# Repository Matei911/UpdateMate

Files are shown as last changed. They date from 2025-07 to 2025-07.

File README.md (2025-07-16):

# UpdateMate

**UpdateMate** is an open-source, low-power ePaper tablet designed for tinkerers, developers, and DIY enthusiasts.  
Built around the ESP32 microcontroller, it offers a customizable platform for displaying relevant, distraction-free information — from weather forecasts and calendar events to news, sensor data, and more.

## Preview

<table>
  <tr>
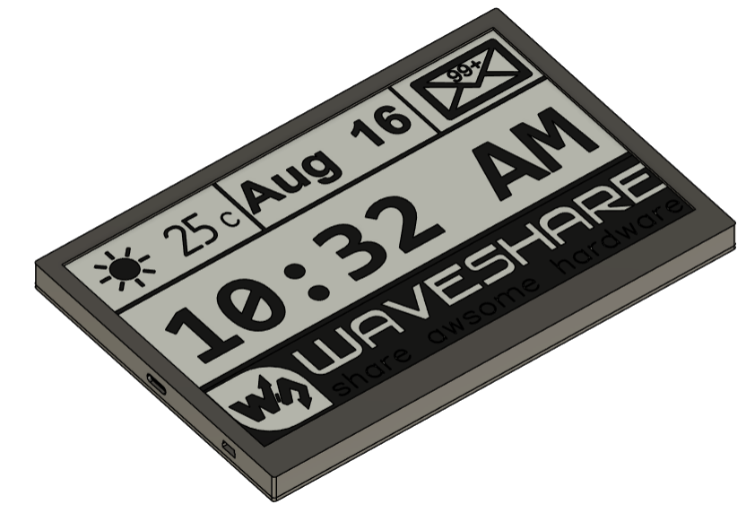
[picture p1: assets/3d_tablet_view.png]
    <td align="center"><br/><sub>3D View of Tablet</sub></td>
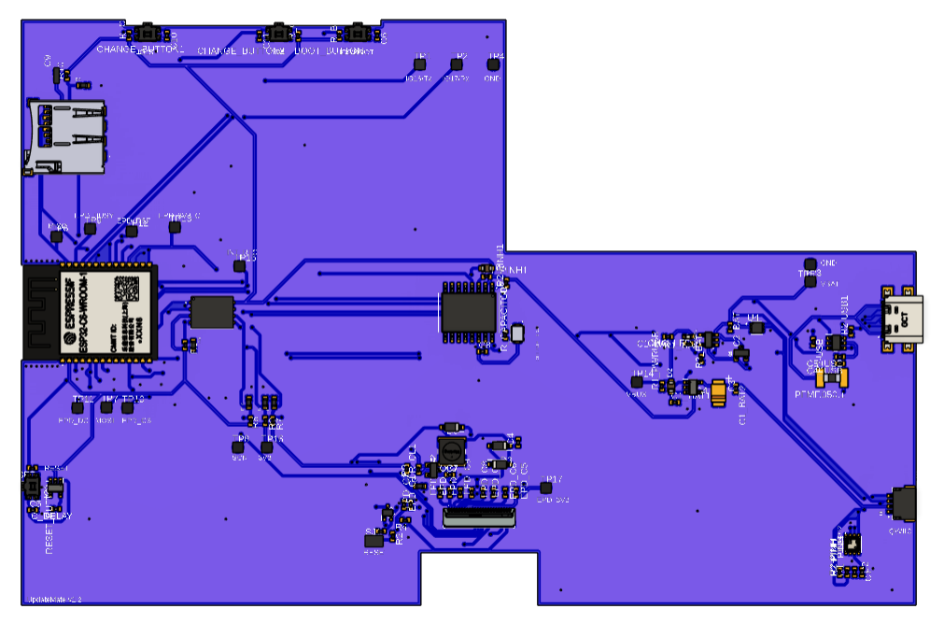
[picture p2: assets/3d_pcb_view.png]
    <td align="center"><br/><sub>3D View of PCB</sub></td>
  </tr>
  <tr>
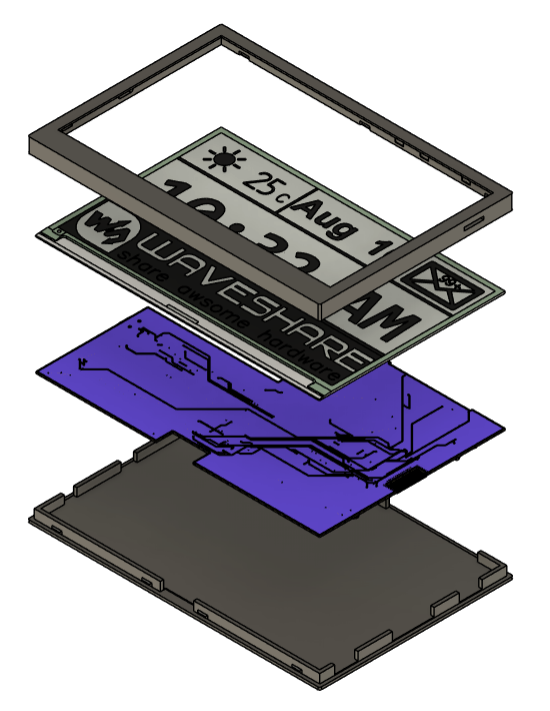
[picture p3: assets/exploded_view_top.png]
    <td align="center"><br/><sub>Exploded View (Top)</sub></td>
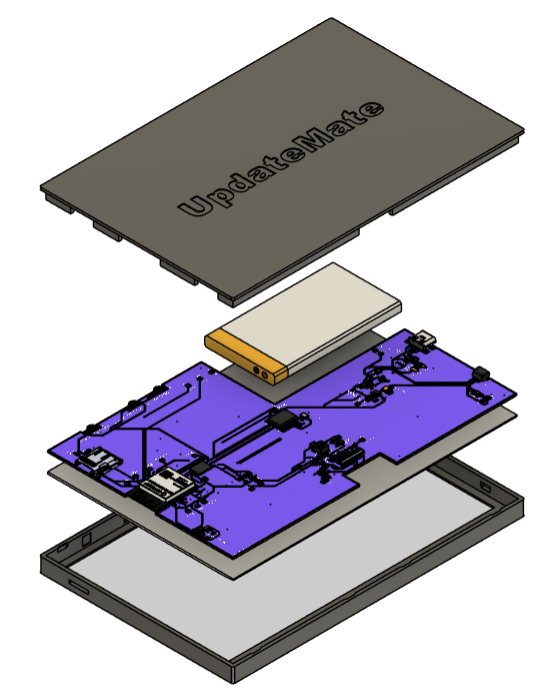
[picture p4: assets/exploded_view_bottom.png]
    <td align="center"><br/><sub>Exploded View (Bottom)</sub></td>
  </tr>
</table>

## Features

- 🖥️ 7.5-inch black-and-white ePaper display from Waveshare  
- ⚡ Low power consumption with deep sleep support  
- 🧩 Rich peripheral support: sensors, SD card, RTC, fuel gauge, and more  
- 🔧 Designed for customization: easily add your own widgets, components, or software

## Ideal for

- 📖 eBook and tablet replacements  
- 🏡 Smart home dashboards  
- 🌦️ Always-on weather/news displays  
- 📅 Personal productivity boards  
- 📡 IoT project front-ends  
- 🧪 Educational embedded systems kits

## Bill of Materials (BoM)

The main components in the tablet

| Component | Interface | Description | Link |
|---|---|---|---|
| **ESP32-C6-WROOM-1-N4**| MCU | Main microcontroller | [Mouser](https://eu.mouser.com/ProductDetail/Espressif-Systems/ESP32-C6-WROOM-1-N4?qs=8Wlm6%252BaMh8R1JRAtXlt87w%3D%3D) |
| **7.5" Waveshare ePaper** | SPI | Black-and-white e-paper display | [Waveshare](https://www.waveshare.com/7.5inch-e-paper.htm) |
| **MicroSD Card Socket** | SPI | For storage and data logging | [TME](https://www.tme.eu/ro/details/mcc-sdmicro/conectori-pentru-cartele/attend/112a-taar-r03/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) |
| **W25Q512JVEIQ NOR Flash** | SPI  | 64 MB external flash memory | [Mouser](https://eu.mouser.com/ProductDetail/Winbond/W25Q512JVEIQ?qs=l7cgNqFNU1jw6svr3at6tA%3D%3D) |
| **MAX17048 Fuel Gauge** | I2C | Battery voltage and state-of-charge monitor | [Mouser](https://eu.mouser.com/ProductDetail/Analog-Devices-Maxim-Integrated/MAX17048G%2bT10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) |
| **BME680 Sensor Board** | I2C | Environmental sensor (temp, humidity, gas)  | [Mouser](https://eu.mouser.com/ProductDetail/Bosch-Sensortec/BME680-Shuttle-Board-3.0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) |
| **DS3231SN RTC** | I2C | Real-time clock with temperature compensation | [Mouser](https://eu.mouser.com/ProductDetail/Analog-Devices-Maxim-Integrated/DS3231SN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) |

## Gallery

Pictures with the features already implemented on the tablet.

<table>
  <tr>
    <td align="center">
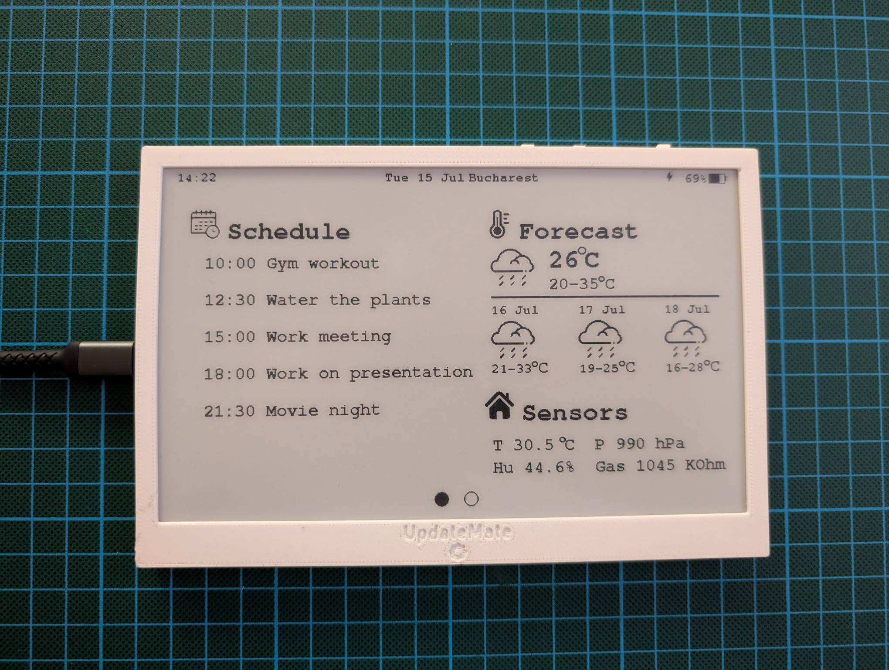
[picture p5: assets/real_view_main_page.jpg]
      <br/>
      <sub>Main Page View</sub>
    </td>
    <td align="center">
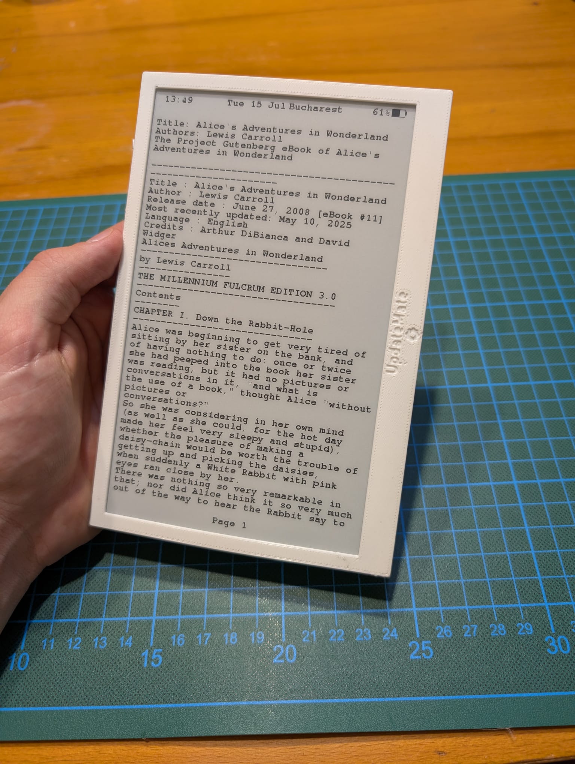
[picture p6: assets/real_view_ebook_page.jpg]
      <br/>
      <sub>eBook Page View</sub>
    </td>
    <td align="center">
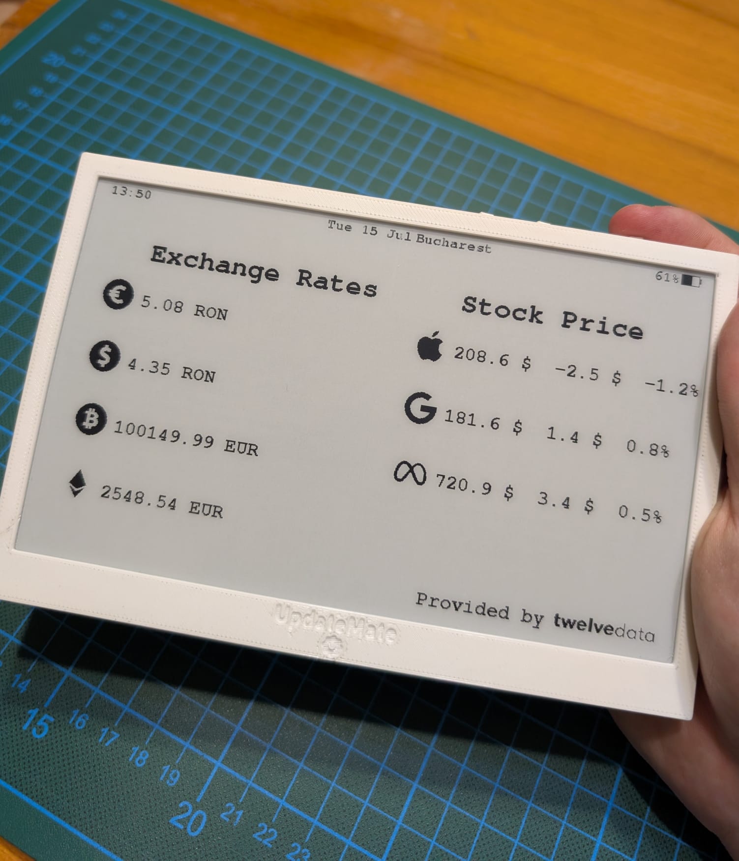
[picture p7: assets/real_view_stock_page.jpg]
      <br/>
      <sub>Stock Page View</sub>
    </td>
  </tr>
  <tr>
    <td align="center">
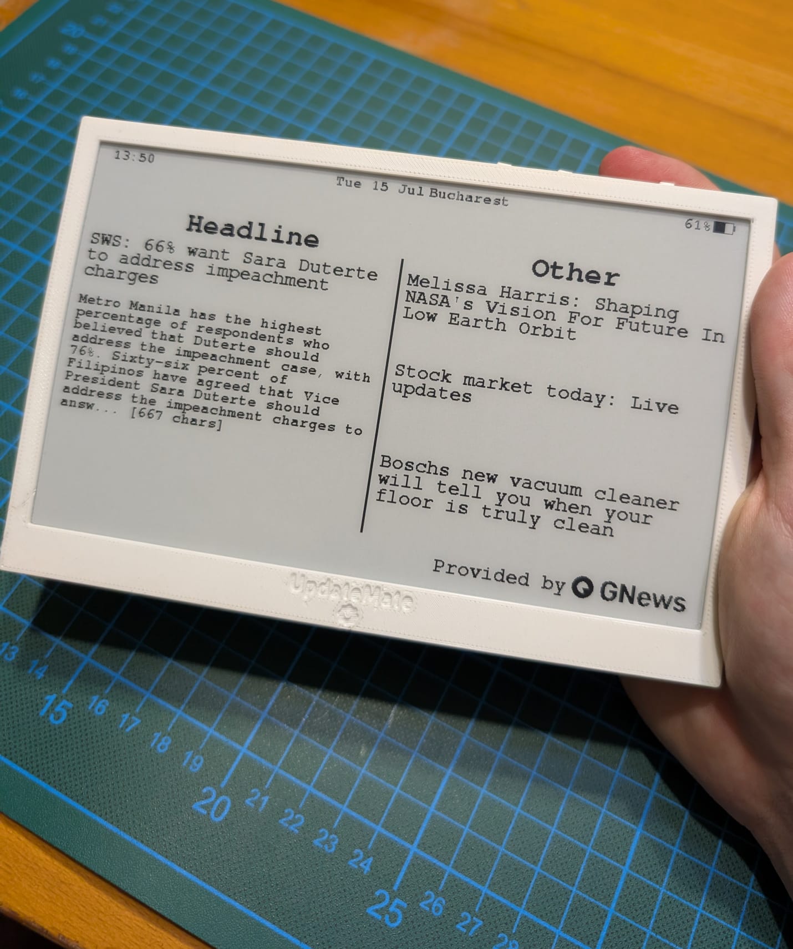
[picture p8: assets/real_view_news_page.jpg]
      <br/>
      <sub>News Page View</sub>
    </td>
    <td align="center">
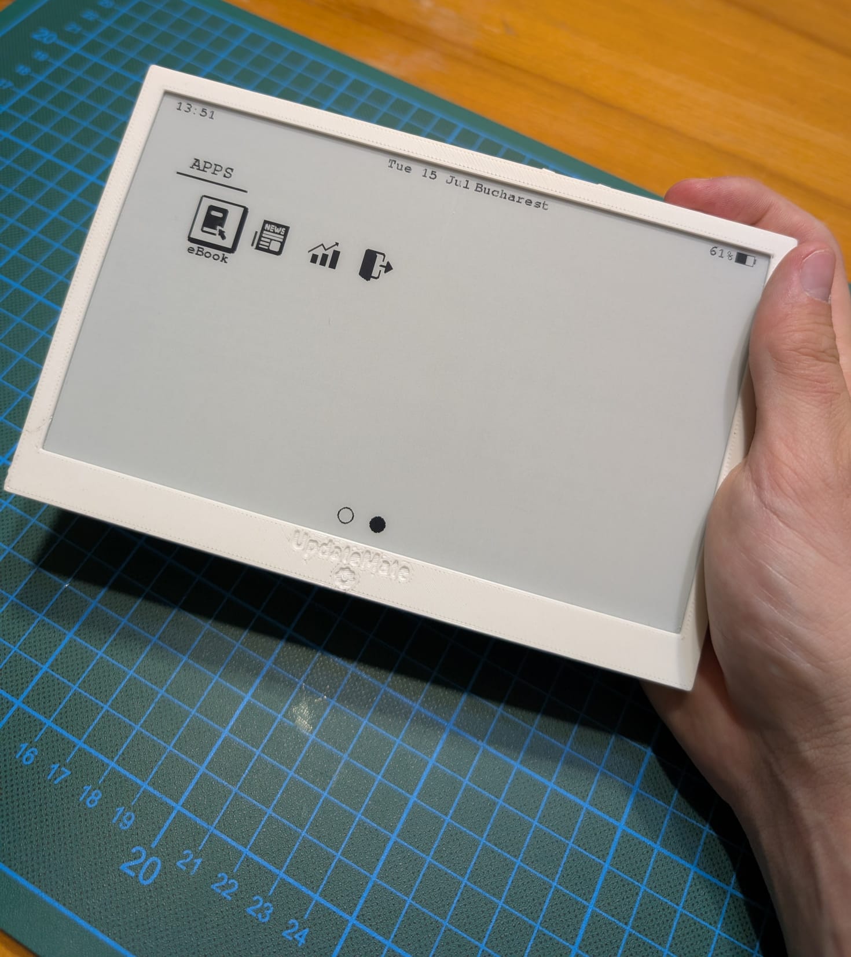
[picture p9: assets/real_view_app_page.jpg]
      <br/>
      <sub>App Launcher View</sub>
    </td>
    <td align="center">
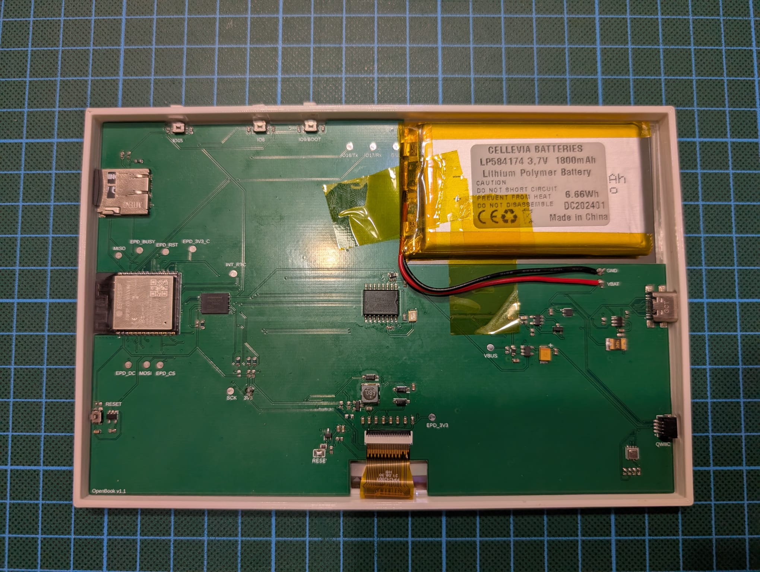
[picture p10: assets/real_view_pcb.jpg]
      <br/>
      <sub>PCB inside case</sub>
    </td>
  </tr>
</table>

## Contents

The repository is structured into two main sections:

### `/hardware`
- Autodesk Fusion 360 design files for the custom PCB  
- 3D model files for the full tablet case, including STL/STEP formats for printing or editing  
- Schematics and layout files for manufacturing the board

### `/software`
- Arduino sketches for individual components (e.g. display, sensors, Wi-Fi, etc.) for testing  
- Full firmware implementation for the UpdateMate tablet, enabling all features shown in the gallery (weather, news, stocks, calendar, eBooks)

**Enjoy tinkering!**

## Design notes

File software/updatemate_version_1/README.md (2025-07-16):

## About This Code 

These files contain the source code for the **UpdateMate tablet**, as featured in the exposed images. The current version supports several core features, including:

- 📅 Google Calendar event display  
- 🌦️ Weather updates  
- 📰 News headlines  
- 📈 Stock price monitoring  
- 📖 Basic eBook reading functionality

Feel free to use the code as-is, customize it for your needs, or improve it.

---

## Before You Flash the Firmware

Please review the following setup requirements:

1. **Partition Scheme**  
   Use the **2MB app / 2MB SPIFFS** partition scheme in your Arduino IDE alonside **ESP32C6 Dev Module**

2. **Uploading Icons**  
   Icon files must be uploaded via the SPIFFS filesystem. This requires an older version of the Arduino IDE.  
   👉 Follow this guide: [Install ESP32 Filesystem Uploader](https://randomnerdtutorials.com/install-esp32-filesystem-uploader-arduino-ide/)

3. **eBook Support**  
   Only `.txt` books are supported in the current version!  
   📚 Visit [Project Gutenberg](https://www.gutenberg.org/) to download free public domain books, then use the provided Python script to convert and upload them.

4. **Google Calendar Integration**  
   You’ll need a custom **Google Apps Script** to expose a private URL that serves your calendar data.  
   ✍️ A template script is included in the repository.

5. **API Keys Required**  
   The following services are used for fetching dynamic data:
   - [Visual Crossing](https://www.visualcrossing.com/) – for weather
   - [Twelve Data](https://twelvedata.com/) – for stock prices
   - [GNews](https://gnews.io/) – for news feed

   🗝️ Sign up for these services to obtain the necessary API keys and insert them into the configuration file.

6. **Enjoy tinkering!**

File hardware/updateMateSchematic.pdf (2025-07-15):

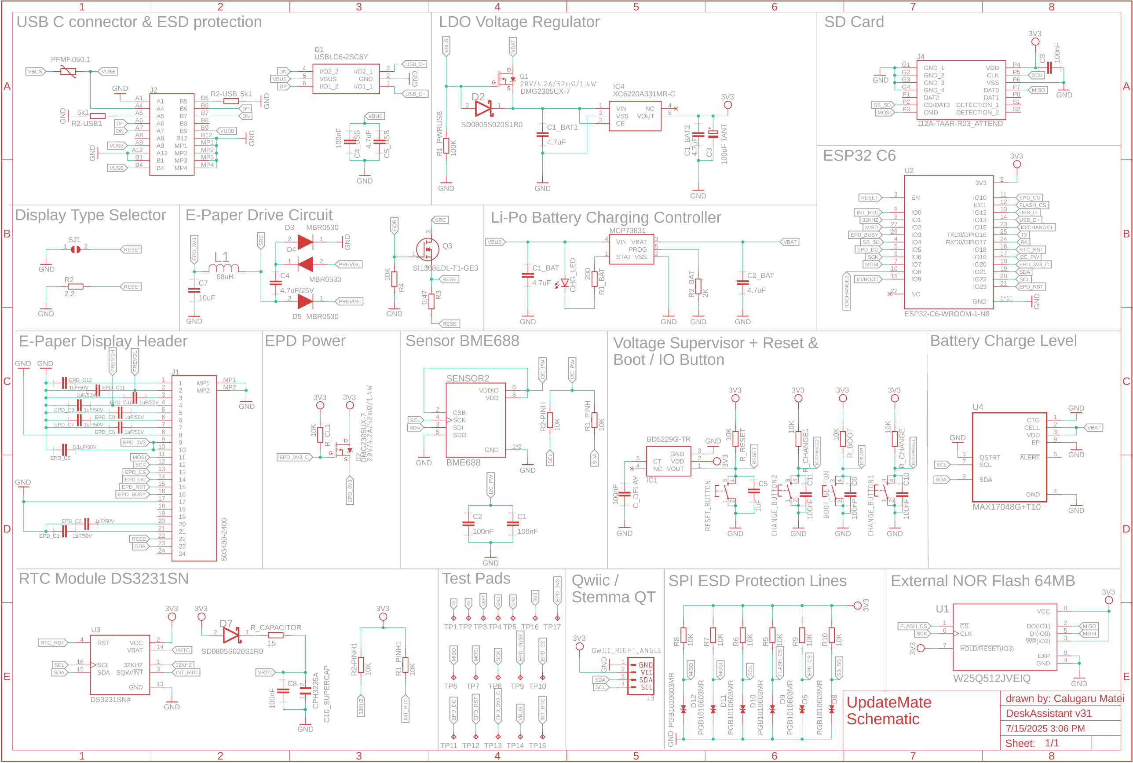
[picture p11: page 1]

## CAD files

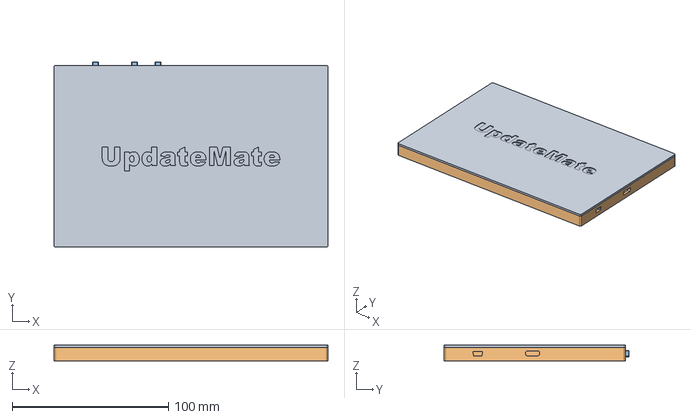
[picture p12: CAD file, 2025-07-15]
hardware/updateMateBox.step
175.2 x 118.5 x 10.2 mm

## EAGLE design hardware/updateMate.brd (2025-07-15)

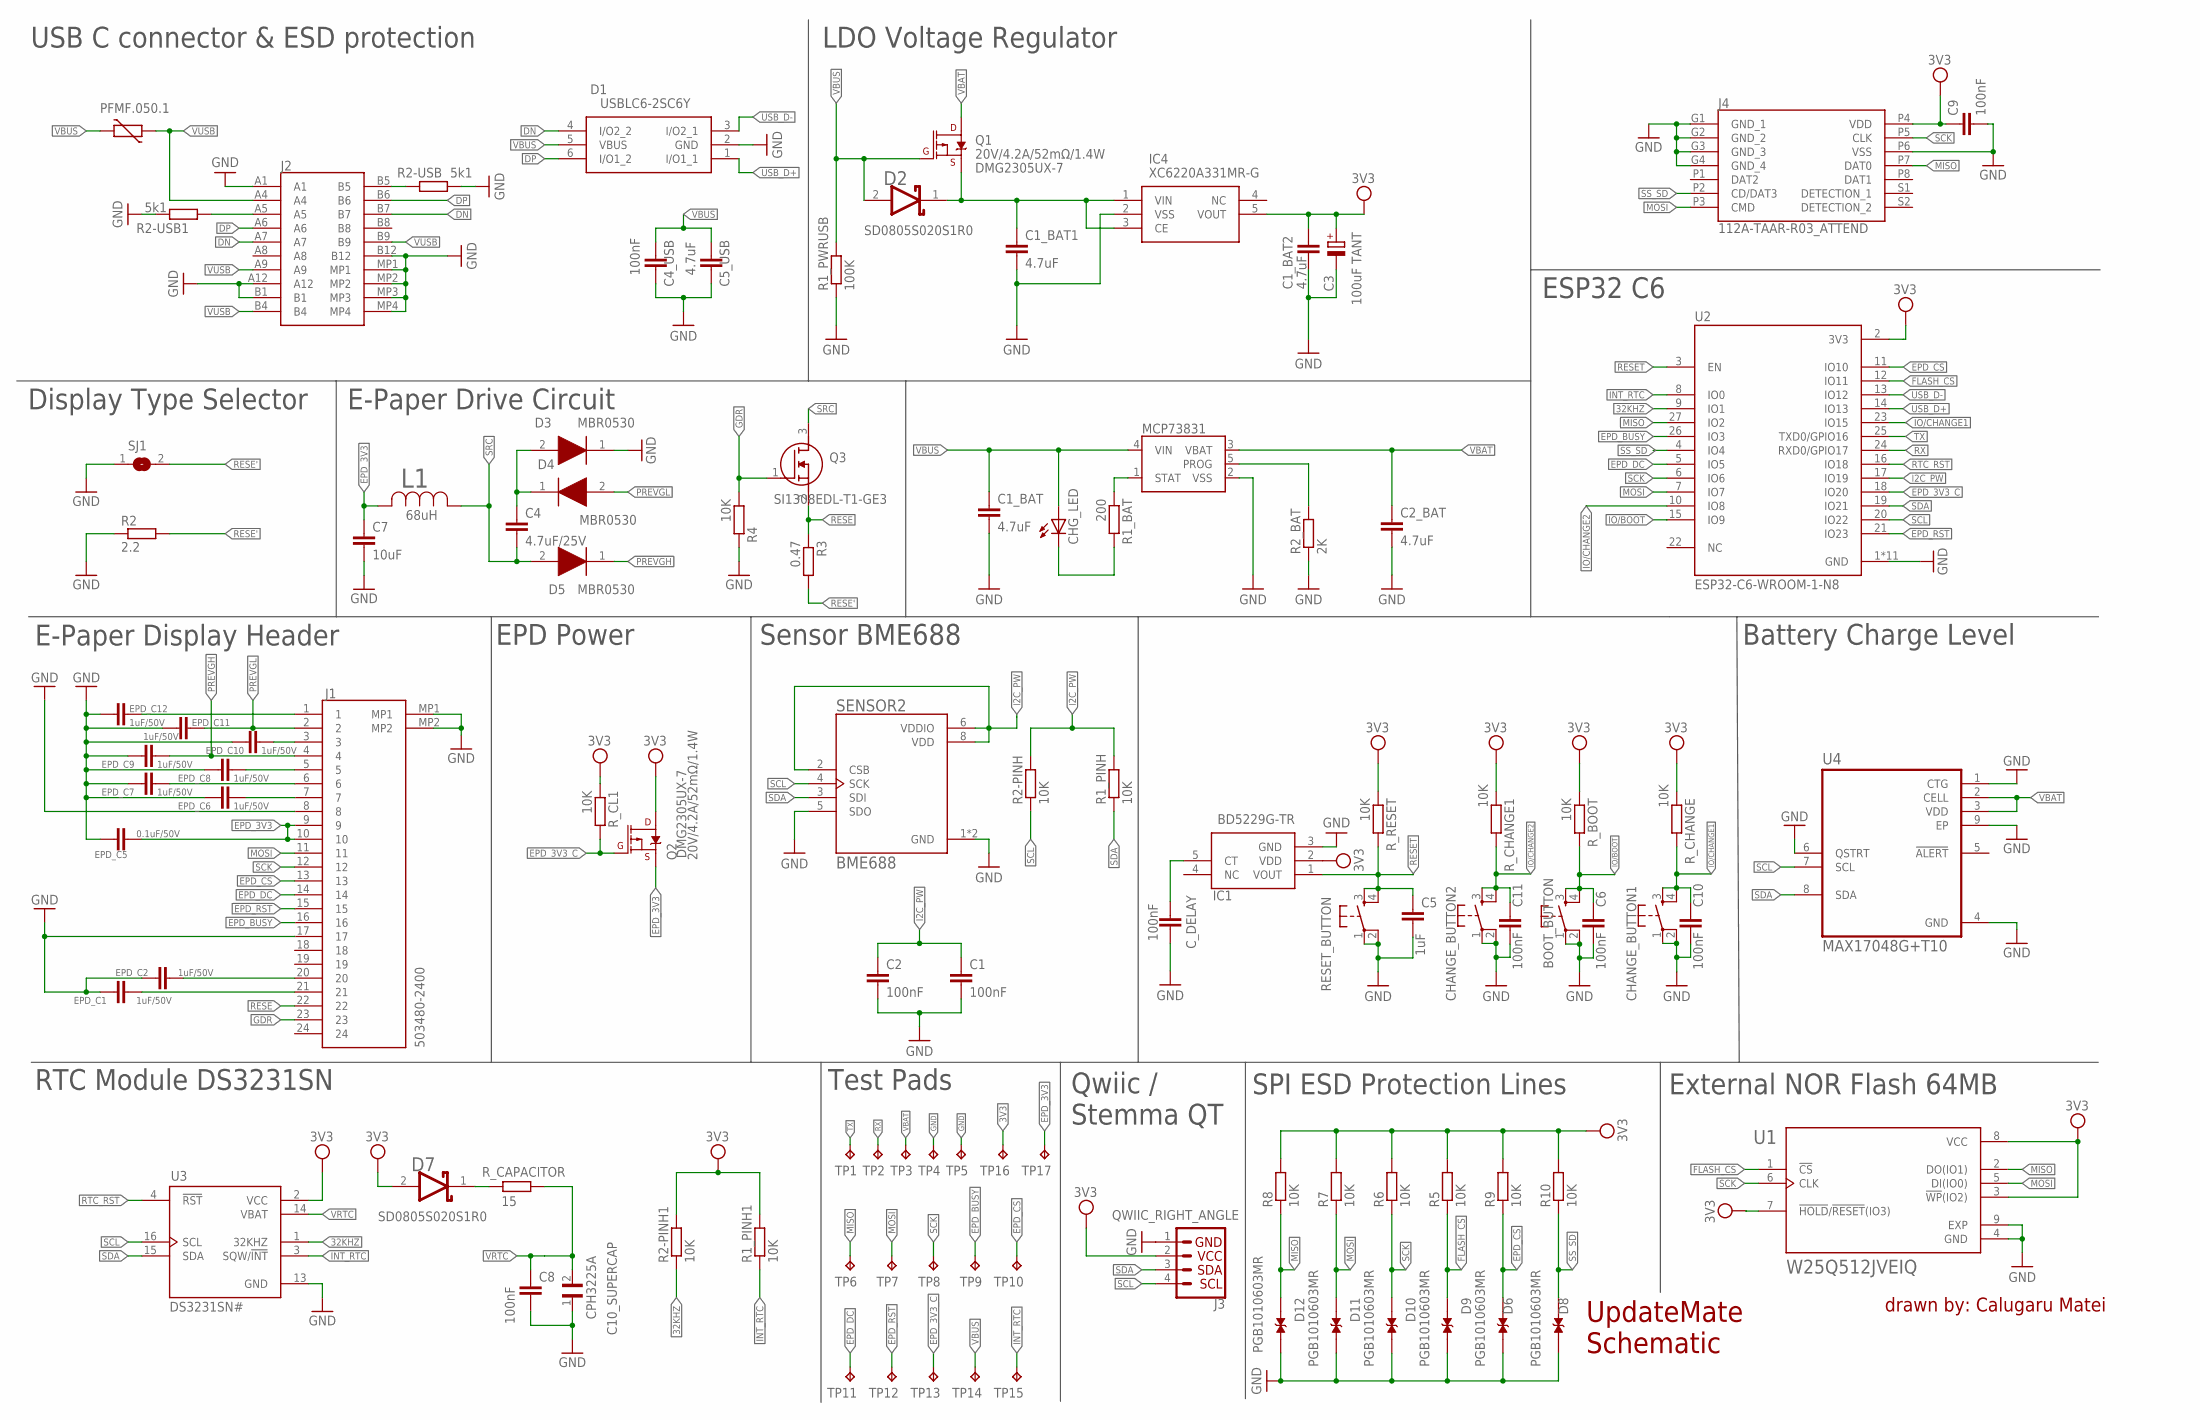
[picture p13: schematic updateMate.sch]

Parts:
BOOT_BUTTON: BUTTON_CUSYOMV1; MYBUTTON
C1, C2, C4_USB, C6, C8, C10, C11: 100nF; ESP32_WROVER_EAGLE-LTSPICE_C0402
C1_BAT, C1_BAT1, C1_BAT2, C2_BAT, C5_USB: 4.7uF; ESP32_WROVER_EAGLE-LTSPICE_C0402
C3: 100uF TANT; RCL_CT3528
C4: 4.7uF/25V; ESP32_WROVER_EAGLE-LTSPICE_C0402
C5: 1uF; ESP32_WROVER_EAGLE-LTSPICE_C0402
C7: 10uF; ESP32_WROVER_EAGLE-LTSPICE_C0402
C9: 100nF; EAGLE-LTSPICE_C0402
C10_SUPERCAP: CPH3225A; CAPCP3225X100N
CHANGE_BUTTON1, CHANGE_BUTTON2: BUTTON_CUSYOMV1; MYBUTTON
CHG_LED: ADAFRUIT_LEDCHIP-LED0603; ADAFRUIT_CHIP-LED0603
C_DELAY: 100nF; ESP32_WROVER_EAGLE-LTSPICE_C0402
D1: USBLC6-2SC6Y; SOT95P280X145-6N
D2: ESP32_WROVER_AVX---SD0805S020S1R0_AVX_SD0805S020S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; ESP32_WROVER_AVX---SD0805S020S1R0_AVX_SD0805S020S1R0_0
D3, D4, D5: MBR0530; SOD3716X135N
D6, D8, D9, D10, D11, D12: PGB1010603MR; DIOC1608X36N
D7: SD0805S020S1R0; ESP32_WROVER_AVX---SD0805S020S1R0_AVX_SD0805S020S1R0_0
EPD_C1, EPD_C2, EPD_C6, EPD_C7, EPD_C8, EPD_C9, EPD_C10, EPD_C11, EPD_C12: 1uF/50V; ESP32_WROVER_EAGLE-LTSPICE_C0402
EPD_C5: 0.1uF/50V; ESP32_WROVER_EAGLE-LTSPICE_C0402
IC1: BD5229G-TR; SOT95P280X125-5N
IC4: XC6220A331MR-G; SOT95P280X120-5N
J1: 503480-2400; 5034802400
J2: SAMACSYS_PARTS_USB4110-GF-A; SAMACSYS_PARTS_USB4110GFA
J3: QWIIC_RIGHT_ANGLE; JST04_1MM_RA
J4: 112A-TAAR-R03_ATTEND; 112ATAARR03ATTEND
L1: 68uH; IND_4828-WE-TPC_WRE
MCP73831: ESP32_WROVER_SPARKFUN-IC-POWER_MCP73831; ESP32_WROVER_SPARKFUN-IC-POWER_SOT23-5
PFMF.050.1: ESP32C6_VARISTORCN1812; ESP32C6_VARISTOR_CT/CN1812
Q1, Q2: 20V/4.2A/52mΩ/1.4W; ESP32_WROVER_SPARKFUN-DISCRETESEMI_SOT23-3
Q3: SI1308EDL-T1-GE3; SOT65P210X110-3N
R1_BAT: 200; ESP32_WROVER_EAGLE-LTSPICE_R0402
R1_PINH, R1_PINH1, R2-PINH, R2-PINH1, R4, R5, R6, R7, R8, R9, R10: 10K; ESP32_WROVER_EAGLE-LTSPICE_R0402
R1_PWRUSB: 100K; ESP32_WROVER_EAGLE-LTSPICE_R0402
R2: 2.2; ESP32_WROVER_EAGLE-LTSPICE_R0402
R2-USB, R2-USB1: 5k1; ESP32_WROVER_EAGLE-LTSPICE_R0402
R2_BAT: 2K; ESP32_WROVER_EAGLE-LTSPICE_R0402
R3: 0.47; ESP32_WROVER_EAGLE-LTSPICE_R0402
RESET_BUTTON: BUTTON_CUSYOMV1; MYBUTTON
R_BOOT: 10K; ESP32_WROVER_EAGLE-LTSPICE_R0402
R_CAPACITOR: 15; ESP32_WROVER_EAGLE-LTSPICE_R0402
R_CHANGE, R_CHANGE1: 10K; ESP32_WROVER_EAGLE-LTSPICE_R0402
R_CL1: 10K; ESP32_WROVER_EAGLE-LTSPICE_R0402
R_RESET: 10K; ESP32_WROVER_EAGLE-LTSPICE_R0402
SENSOR2: BME688; ESP32_WROVER_BME680_PSON80P300X300X100-8N
SJ1: SJ
TP1, TP2, TP3, TP4, TP5, TP6, TP7, TP8, TP9, TP10, TP11, TP12, TP13, TP14, TP15, TP16, TP17: TPTP20R; TP20R
U1: W25Q512JVEIQ; SON127P600X800X80-9N
U2: ESP32-C6-WROOM-1-N8; XCVR_ESP32-C6-WROOM-1-N8
U3: DS3231SN#; SOIC127P1032X265-16N
U4: MAX17048G+T10; SON50P200X200X80-9N

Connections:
3V3: C1_BAT2.1, C3.+, C9.1, D7.2 (ANODE), IC1.2 (VDD), IC4.5 (VOUT), J3.2, J4.P4 (VDD), Q2.3 (D), R1_PINH1.2, R2-PINH1.2, R5.2, R6.2, R7.2, R8.2, R9.2, R10.2, R_BOOT.1, R_CHANGE.1, R_CHANGE1.1, R_CL1.1, R_RESET.1, TP16.TP, U1.3 (!WP!(IO2)), U1.7 (!HOLD!/!RESET!(IO3)), U1.8 (VCC), U2.2 (3V3), U3.2 (VCC)
32KHZ: R2-PINH1.1, U2.9 (IO1), U3.1 (32KHZ)
DN: D1.4 (I/O2_2), J2.A7, J2.B7
DP: D1.6 (I/O1_2), J2.A6, J2.B6
EPD_3V3: C7.1, EPD_C5.1, J1.9, J1.10, L1.2, Q2.2 (S), TP17.TP
EPD_3V3_C: Q2.1 (G), R_CL1.2, TP13.TP, U2.18 (IO20)
EPD_BUSY: J1.16, TP9.TP, U2.26 (IO3)
EPD_CS: D6.1, J1.13, R9.1, TP10.TP, U2.11 (IO10)
EPD_DC: J1.14, TP11.TP, U2.5 (IO5)
EPD_RST: J1.15, TP12.TP, U2.21 (IO23)
FLASH_CS: D9.1, R5.1, U1.1 (!CS), U2.12 (IO11)
GDR: J1.23, Q3.1 (G), R4.1
GND: BOOT_BUTTON.1, BOOT_BUTTON.2, C1.2, C1_BAT.2, C1_BAT1.2, C1_BAT2.2, C2.2, C2_BAT.2, C3.-, C4_USB.2, C5.2, C5_USB.2, C6.2, C7.2, C8.2, C9.2, C10.2, C10_SUPERCAP.1, C11.2, CHANGE_BUTTON1.1, CHANGE_BUTTON1.2, CHANGE_BUTTON2.1, CHANGE_BUTTON2.2, C_DELAY.2, D1.2 (GND), D3.1 (K), D6.2, D8.2, D9.2, D10.2, D11.2, D12.2, EPD_C1.2, EPD_C2.2, EPD_C5.2, EPD_C6.2, EPD_C7.2, EPD_C8.2, EPD_C9.2, EPD_C10.2, EPD_C11.2, EPD_C12.2, IC1.3 (GND), IC4.2 (VSS), J1.8, J1.17, J1.MP1, J1.MP2, J2.A1, J2.A12, J2.B1, J2.B12, J2.MP1, J2.MP2, J2.MP3, J2.MP4, J3.1, J4.G1 (GND_1), J4.G2 (GND_2), J4.G3 (GND_3), J4.G4 (GND_4), J4.P6 (VSS), MCP73831.2 (VSS), R1_PWRUSB.1, R2.1, R2-USB.2, R2-USB1.1, R2_BAT.1, R4.2, RESET_BUTTON.1, RESET_BUTTON.2, SENSOR2.1 (GND), SENSOR2.5 (SDO), SENSOR2.7 (GND), SJ1.1, TP4.TP, TP5.TP, U1.4 (GND), U1.9 (EXP), U2.1 (GND), U2.28 (GND), U2.29_1 (GND), U2.29_2 (GND), U2.29_3 (GND), U2.29_4 (GND), U2.29_5 (GND), U2.29_6 (GND), U2.29_7 (GND), U2.29_8 (GND), U2.29_9 (GND), U3.13 (GND), U4.1 (CTG), U4.4 (GND), U4.6 (QSTRT), U4.9 (EP)
I2C_PW: C1.1, C2.1, R1_PINH.2, R2-PINH.2, SENSOR2.2 (CSB), SENSOR2.6 (VDDIO), SENSOR2.8 (VDD), U2.17 (IO19)
INT_RTC: R1_PINH1.1, TP15.TP, U2.8 (IO0), U3.3 (SQW/!INT)
IO/BOOT: BOOT_BUTTON.3, BOOT_BUTTON.4, C6.1, R_BOOT.2, U2.15 (IO9)
IO/CHANGE1: C10.1, CHANGE_BUTTON1.3, CHANGE_BUTTON1.4, R_CHANGE.2, U2.23 (IO15)
IO/CHANGE2: C11.1, CHANGE_BUTTON2.3, CHANGE_BUTTON2.4, R_CHANGE1.2, U2.10 (IO8)
MISO: D12.1, J4.P7 (DAT0), R8.1, TP6.TP, U1.2 (DO(IO1)), U2.27 (IO2)
MOSI: D11.1, J1.11, J4.P3 (CMD), R7.1, TP7.TP, U1.5 (DI(IO0)), U2.7 (IO7)
unnamed: J2.B5, R2-USB.1
unnamed: C_DELAY.1, IC1.5 (CT)
unnamed: C1_BAT1.1, D2.1 (CATHODE), IC4.1 (VIN), IC4.3 (CE), Q1.2 (S)
unnamed: J2.A5, R2-USB1.2
unnamed: D7.1 (CATHODE), R_CAPACITOR.2
unnamed: EPD_C1.1, J1.21
unnamed: EPD_C2.1, J1.20
unnamed: C4.1, D3.2 (A), D4.1 (K)
unnamed: MCP73831.5 (PROG), R2_BAT.2
unnamed: MCP73831.1 (STAT), R1_BAT.1
unnamed: CHG_LED.C, R1_BAT.2
unnamed: EPD_C6.1, J1.7
unnamed: EPD_C7.1, J1.6
unnamed: EPD_C8.1, J1.5
unnamed: EPD_C10.1, J1.3
unnamed: EPD_C12.1, J1.1
PREVGH: D5.1 (K), EPD_C9.1, J1.4
PREVGL: D4.2 (A), EPD_C11.1, J1.2
RESE: J1.22, Q3.2 (S), R3.1
RESE': R2.2, R3.2, SJ1.2
RESET: C5.1, IC1.1 (VOUT), RESET_BUTTON.3, RESET_BUTTON.4, R_RESET.2, U2.3 (EN)
RTC_RST: U2.16 (IO18), U3.4 (!RST)
RX: TP2.TP, U2.24 (RXD0/GPIO17)
SCK: D10.1, J1.12, J4.P5 (CLK), R6.1, TP8.TP, U1.6 (CLK), U2.6 (IO6)
SCL: J3.4, R2-PINH.1, SENSOR2.4 (SCK), U2.20 (IO22), U3.16 (SCL), U4.7 (SCL)
SDA: J3.3, R1_PINH.1, SENSOR2.3 (SDI), U2.19 (IO21), U3.15 (SDA), U4.8 (SDA)
SRC: C4.2, D5.2 (A), L1.1, Q3.3 (D)
SS_SD: D8.1, J4.P2 (CD/DAT3), R10.1, U2.4 (IO4)
TX: TP1.TP, U2.25 (TXD0/GPIO16)
USB_D+: D1.1 (I/O1_1), U2.14 (IO13)
USB_D-: D1.3 (I/O2_1), U2.13 (IO12)
VBAT: C2_BAT.1, MCP73831.3 (VBAT), Q1.3 (D), TP3.TP, U4.2 (CELL), U4.3 (VDD)
VBUS: C1_BAT.1, C4_USB.1, C5_USB.1, CHG_LED.A, D1.5 (VBUS), D2.2 (ANODE), MCP73831.4 (VIN), PFMF.050.1.1, Q1.1 (G), R1_PWRUSB.2, TP14.TP
VRTC: C8.1, C10_SUPERCAP.2, R_CAPACITOR.1, U3.14 (VBAT)
VUSB: J2.A4, J2.A9, J2.B4, J2.B9, PFMF.050.1.2

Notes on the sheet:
USB C connector & ESD protection
LDO Voltage Regulator
Battery Charge Level
Sensor BME688
ESP32 C6
Qwiic / Stemma QT
External NOR Flash 64MB
E-Paper Display Header
Display Type Selector
E-Paper Drive Circuit
SPI ESD Protection Lines
EPD Power
RTC Module DS3231SN
Test Pads
SD0805S020S1R0
68uH
drawn by: Calugaru Matei
UpdateMate Schematic
DMG2305UX-7

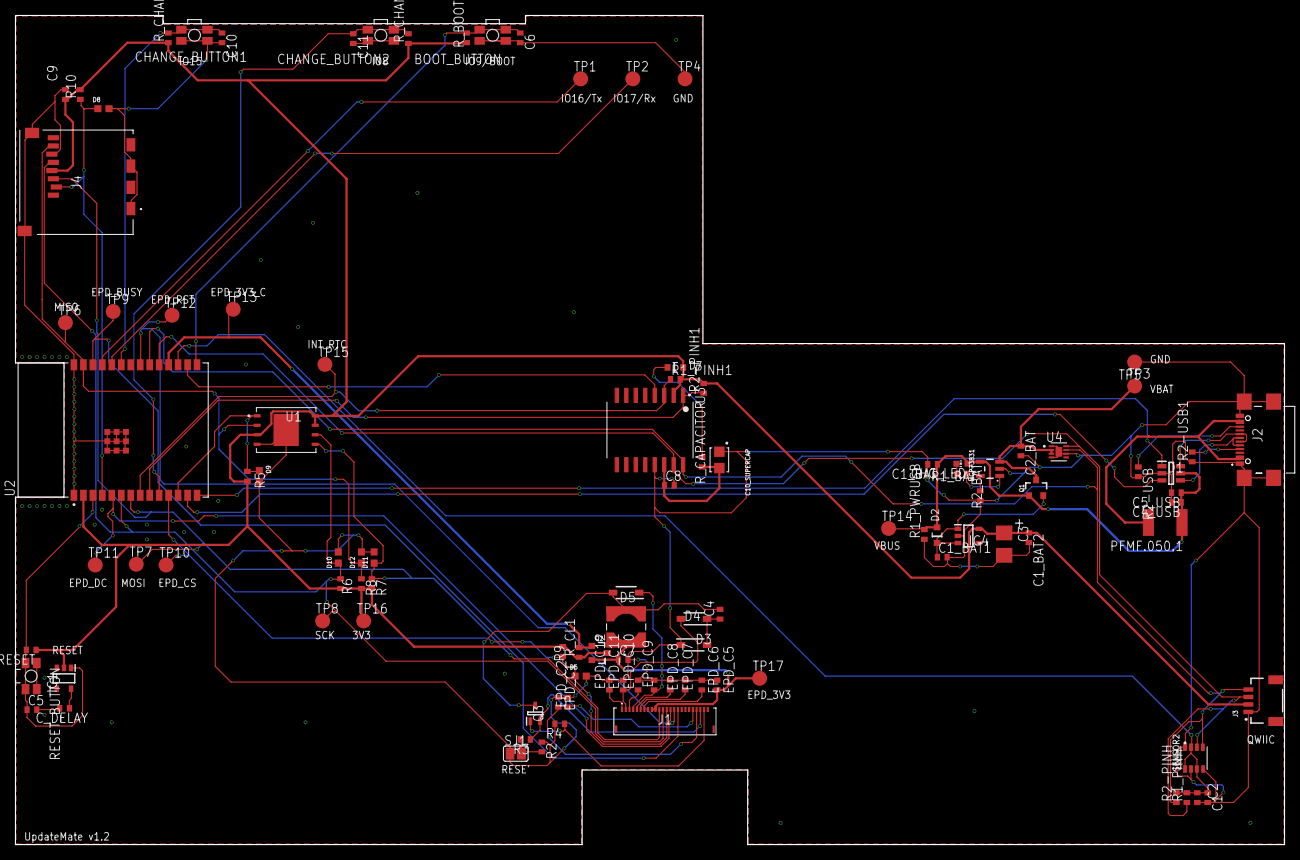
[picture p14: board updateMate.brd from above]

Board: 2 copper layers, 170.2 x 111.2 mm, 105 parts (0 on the bottom side), 55 nets.

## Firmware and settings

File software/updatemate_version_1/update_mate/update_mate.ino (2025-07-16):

#include "drawPage1.h"
#include "drawPage2.h"
#include "drawPage3.h"
#include "drawNews.h"
#include "drawStocks.h"
#include <SPIFFS.h>
#include <Wire.h>
#include "config.h"
#include <SD.h>

SPIClass spi = SPIClass(FSPI);
volatile bool bookTime = false;

void printDirectory(File dir, int numTabs) {
  while (true) {
    File entry = dir.openNextFile();
    if (!entry) break;  // no more
    for (int i = 0; i < numTabs; i++) Serial.print('\t');
    Serial.print(entry.name());
    if (entry.isDirectory()) {
      Serial.println("/");
      printDirectory(entry, numTabs + 1);
    } else {
      Serial.print("\t\t");
      Serial.println(entry.size(), DEC);
    }
    entry.close();
  }
}

IRAM_ATTR void rightButtonISR() {
  unsigned long now = millis();
  if (now - lastDebounceRight < debounceDelay) return;
  lastDebounceRight = now;

  if (page == 3 && !selectBooks) {
    // if in book view, scroll in books content
    scrollLine += scrollStep;
    pageChanged = true;
    return;
  }
  if (page == 3 && selectBooks) {
    // select book
    selectedBookIndex = (selectedBookIndex + maxBookIdx) % (maxBookIdx + 1);
    pageChanged = true;
    return;
  }
  // 1) block left/right while in an app page
  if (page >= 3) return;

  // 2) if we’re on page 2 in selection mode, move through icons
  if (page == 2 && selectionMode) {
    selectedCategory--;
    if (selectedCategory < 0) selectedCategory = 3;
    pageChanged = true;
    return;
  }

  // 3) otherwise, move between page 1 and 2
  if (page > 1) {
    page--;
    pageChanged = true;
  }
}

IRAM_ATTR void leftButtonISR() {
  unsigned long now = millis();
  if (now - lastDebounceLeft < debounceDelay) return;
  lastDebounceLeft = now;

  if (page == 3 && selectBooks) {
    selectedBookIndex = (selectedBookIndex + 1) % (maxBookIdx + 1);
    pageChanged = true;
    return;
  }
  if (page == 3 && !selectBooks) {
    scrollLine = max(0, scrollLine - scrollStep);
    pageChanged = true;
    return;
  }
  if (page >= 3) return;
  if (page == 2 && selectionMode) {
    selectedCategory++;
    if (selectedCategory > 3) selectedCategory = 0;
    pageChanged = true;
    return;
  }

  if (page < 2) {
    page++;
    pageChanged = true;
  }
}
IRAM_ATTR void enterButtonISR() {
  unsigned long now = millis();
  if (now - lastDebounceEnter < debounceDelay) return;
  lastDebounceEnter = now;

  // --- Page 3: either start selecting, show book, or go back to list/exit ---
  if (page == 3) {
    // If you're currently on the list, and you press Enter on a valid book:
    if (selectBooks && selectedBookIndex < maxBookIdx) {
      // switch into "show book" mode
      selectBooks = false;
      scrollLine = 0;
      bookTime = true;
    } else if (!selectBooks) {
      // already showing the book, pressing Enter returns to the list
      selectBooks = true;
      listNeedsFullRefresh = true;
      bookTime = false;
    } else {
      // selectBooks && selectedBookIndex == maxBookIdx → Exit entry
      page = 2;
      selectionMode = true;
      selectBooks = false;  // reset for next time
    }

    pageChanged = true;
    return;
  }

  // --- Page 2: app menu selection / launch ---
  if (page == 2) {
    if (!selectionMode) {
      selectionMode = true;
      selectedCategory = 0;
    } else {
      switch (selectedCategory) {
        case 0:  // eBook
          page = 3;
          selectBooks = true;
          selectedBookIndex = 0;
          scrollLine = 0;
          listNeedsFullRefresh = true;
          break;
        case 1: page = 4; break;  // News
        case 2: page = 5; break;  // Stocks
        case 3: page = 1; break;  // Exit
      }
      selectionMode = false;
    }
    pageChanged = true;
    return;
  }
  // Enter and exit the stocks and news app
  if (page == 4 || page == 5) {
    page = 2;
    selectionMode = true;
    pageChanged = true;
  }
}
void initDisplay() {
  Serial.begin(115200);
  Serial.println("SET");

  pinMode(20, OUTPUT);
  digitalWrite(20, LOW);
  delay(1000);

  mySPI.begin(SD_SCK, SD_MISO, SD_MOSI, SD_CS);
  display.epd2.selectSPI(mySPI, SPISettings(4000000, MSBFIRST, SPI_MODE0));
  display.init(115200, true, 2, false);
}

void initSDcard() {
  Serial.println("Mounting SD card…");
  if (!SD.begin(SD_CS, mySPI)) {
    Serial.println("SD init failed!");
  } else {
    Serial.println("SD initialized");
    // List files:
    Serial.println("Files on SD:");
    File root = SD.open("/");
    printDirectory(root, 0);
    root.close();
  }
}

void setup() {
  initDisplay();
  initSDcard();
  // Setup buttons and attach interrupts
  pinMode(RIGHT_BUT, INPUT_PULLUP);
  pinMode(LEFT_BUT, INPUT_PULLUP);
  pinMode(ENTER_BUT, INPUT_PULLUP);
  attachInterrupt(digitalPinToInterrupt(RIGHT_BUT), rightButtonISR, FALLING);
  attachInterrupt(digitalPinToInterrupt(LEFT_BUT), leftButtonISR, FALLING);
  attachInterrupt(digitalPinToInterrupt(ENTER_BUT), enterButtonISR, FALLING);

  // Connect to WiFi.
  WiFi.begin(ssid, password);
  Serial.println("WiFi..");
  int wifi_retries = 0;
  while (WiFi.status() != WL_CONNECTED && wifi_retries < 20) {
    delay(500);
    Serial.print(".");
    wifi_retries++;
  }
  if (WiFi.status() != WL_CONNECTED) {
    Serial.println("\nWiF Err!");
  } else {
    Serial.println("\nWiF OK");
    Serial.print("IP: ");
    Serial.println(WiFi.localIP());
  }

  // Initialize SPIFFS
  Serial.println("SPI..");
  if (!SPIFFS.begin(true)) {
    Serial.println("SPI Err!");
  } else {
    Serial.println("SPI OK");
  }

  // Power on I2C
  pinMode(I2C_POWER_PIN, OUTPUT);
  digitalWrite(I2C_POWER_PIN, HIGH);
  Wire.begin(SDA_PIN, SCL_PIN);

  // Initialize sensors
  if (!initSensors()) {
    Serial.println("Sens Err!");
    while (1)
      ;
  } else {
    Serial.println("Sens OK");
  }
  updateSensorData(sensorDataFinal);
  // Fetch calendar data once on boot
  fetchCalendarData();
  if (sensorDataFinal.rtcTime.hour() > CALENDAR_FETCH_HOUR || (sensorDataFinal.rtcTime.hour() == CALENDAR_FETCH_HOUR && sensorDataFinal.rtcTime.minute() >= CALENDAR_FETCH_MINUTE)) {
    calendarFetchedToday = true;
    Serial.println("Cal set");
  } else {
    calendarFetchedToday = false;
    Serial.println("Cal clr");
  }

  // Draw initial display (Page 1).
  fullRefreshPage1();

  lastRefreshTime = sensorDataFinal.rtcTime;
  Serial.print("R: ");
  Serial.println(lastRefreshTime.timestamp(DateTime::TIMESTAMP_FULL));
}
void ensureWiFi() {
  if (WiFi.status() == WL_CONNECTED) return;
  Serial.println("WiFi lost! Reconnecting...");
  WiFi.disconnect();
  WiFi.begin(ssid, password);
  for (int i = 0; i < 20 && WiFi.status() != WL_CONNECTED; i++) {
    delay(500);
    Serial.print(".");
  }
  Serial.println(WiFi.status() == WL_CONNECTED ? "\nWiFi OK" : "\nWiFi Err!");
}
void handlePage(int pg,
                DateTime& lastRef,
                DateTime& lastClk,
                void (*fullRefresh)(),
                void (*partialClock)(const DateTime&)) {
  if (page != pg) return;
  DateTime now = sensorDataFinal.rtcTime;
  // do a full refresh for the content
  if ((now - lastRef).totalseconds() >= rtcRefreshIntervalSeconds) {
    ensureWiFi();
    Serial.printf("RTC ref (page %d)\n", pg);
    fullRefresh();
    lastRef = now;
    lastClk = now;
    Serial.print("Ref");
    Serial.println(lastRef.timestamp(DateTime::TIMESTAMP_FULL));
  }
  // do a partial refreash for the clock
  if ((now - lastClk).totalseconds() >= rtcClockUpdate) {
    partialClock(now);
    lastClk = now;
  }
}

void loop() {
  if (pageChanged) {
    pageChanged = false;
    switch (page) {
      case 1:
        fullRefreshPage1();
        lastRefreshTime = sensorDataFinal.rtcTime;
        break;
      case 2:
        fullRefreshPage2();
        lastRefreshTime = sensorDataFinal.rtcTime;
        break;
      case 3:
        fullRefreshPage3();
        lastRefreshTime = sensorDataFinal.rtcTime;
        break;
      case 4:
        fullRefreshPageNews();
        lastRefreshTime = sensorDataFinal.rtcTime;
        break;
      case 5:
        fullRefreshPageStocks();
        lastRefreshTime = sensorDataFinal.rtcTime;
        break;
    }
  }

  updateSensorData(sensorDataFinal);
  // Daily Calendar Fetch Check at 00:10
  if (sensorDataFinal.rtcTime.hour() == CALENDAR_FETCH_HOUR && sensorDataFinal.rtcTime.minute() < CALENDAR_FETCH_MINUTE) {
    if (calendarFetchedToday) {
      Serial.println("Cal reset");
      calendarFetchedToday = false;
    }
  }
  if (sensorDataFinal.rtcTime.hour() < CALENDAR_FETCH_HOUR) {
    if (calendarFetchedToday) {
      Serial.println("Cal reset");
      calendarFetchedToday = false;
    }
  }
  if (sensorDataFinal.rtcTime.hour() == CALENDAR_FETCH_HOUR && sensorDataFinal.rtcTime.minute() == CALENDAR_FETCH_MINUTE && !calendarFetchedToday) {
    Serial.println("Cal fetch");
    fetchCalendarData();
    fullRefreshPage1();
    lastRefreshTime = sensorDataFinal.rtcTime;
  }

  handlePage(1, lastRefreshTime, lastClockUpdate, fullRefreshPage1, drawClockPartialFinal);
  handlePage(2, lastRefreshTime, lastClockUpdate, fullRefreshPage2, drawClockPartialFinal);
  if (bookTime == false) {
    handlePage(3, lastRefreshTime, lastClockUpdate, fullRefreshPage3, drawClockPartialFinal);
  } else {
    handlePage(3, lastRefreshTime, lastClockUpdate, fullRefreshPage3, drawClockPartialBook);
  }
  handlePage(4, lastRefreshTime, lastClockUpdate, fullRefreshPageNews, drawClockPartialFinal);
  handlePage(5, lastRefreshTime, lastClockUpdate, fullRefreshPageStocks, drawClockPartialFinal);
  delay(200);
}

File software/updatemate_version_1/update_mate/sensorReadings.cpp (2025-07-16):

#include "sensorReadings.h"


#define BME688_ADDRESS 0x76

Adafruit_BME680 bme;
RTC_DS3231 rtc;
SFE_MAX1704X lipo(MAX1704X_MAX17048);


const char* getDayName(uint8_t day) {
  const char* days[] = { "Sun", "Mon", "Tue", "Wed", "Thu", "Fri", "Sat" };
  if (day < 7) return days[day];
  return "";
}

const char* getMonthName(uint8_t month) {
  const char* months[] = {
    "",
    "Jan", "Feb", "Mar", "Apr", "May", "Jun",
    "Jul", "Aug", "Sep", "Oct", "Nov", "Dec"
  };
  if (month >= 1 && month <= 12) return months[month];
  return "";
}


bool initSensors() {
  bool success = true;

  Serial.println("Init BME688");
  if (!bme.begin(BME688_ADDRESS, &Wire)) {
    Serial.println("No BME");
    success = false;
  } else {
    bme.setTemperatureOversampling(BME680_OS_8X);
    bme.setHumidityOversampling(BME680_OS_2X);
    bme.setPressureOversampling(BME680_OS_4X);
    bme.setIIRFilterSize(BME680_FILTER_SIZE_3);
    bme.setGasHeater(320, 150);
    Serial.println("BME688 success");
  }

  Serial.println("Init RTC");
  if (!rtc.begin()) {
    Serial.println("No RTC");
  } else {
    if (rtc.lostPower()) {
      Serial.println("Reinit RTC");
      rtc.adjust(DateTime(F(__DATE__), F(__TIME__)));
    }
    //rtc.adjust(DateTime(F(__DATE__), F(__TIME__)));
    //rtc.adjust(DateTime(2025, 7, 15, 16, 18, 0));
    Serial.println("RTC init");
  }

  Serial.println("Init MAX");

  if (!lipo.begin()) {
    Serial.println(F("No MAX"));
    success = false;
  } else {
    Serial.println("MAX sucess");
    //lipo.quickStart();
  }


  return success;
}


void updateSensorData(SensorData& data) {
  if (!bme.performReading()) {
    Serial.println("Fail BME read");
  }
  data.temperature = bme.temperature;
  data.humidity = bme.humidity;
  data.pressure = bme.pressure / 100.0;
  data.gasResistance = bme.gas_resistance / 1000.0;

  // Read RTC
  data.rtcTime = rtc.now();

  // Read MAX1704x
  data.batteryVoltage = lipo.getVoltage();
  data.batterySOC = lipo.getSOC();
  data.batteryChg = lipo.getChangeRate();
}

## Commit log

2025-07-15 Adding BOM
2025-07-15 Adding schematics and CAD Files
    [updateMate.brd, updateMate.sch]
2025-07-15 Adding case 3D model
    [updateMateBox.step]

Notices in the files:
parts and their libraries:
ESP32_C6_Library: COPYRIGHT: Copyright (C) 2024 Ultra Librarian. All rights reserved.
